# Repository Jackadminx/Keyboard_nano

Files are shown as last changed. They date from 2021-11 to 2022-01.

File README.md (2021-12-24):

# Keyboard nano

基于CH549的多功能小键盘

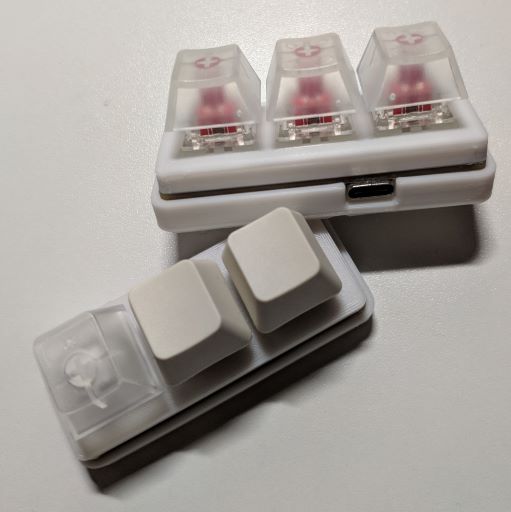
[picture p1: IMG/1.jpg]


## 功能

硬件

- 热拔插键轴
- WS2812 RGB
- CH549主控 8051
- Type-C 接口
- 3D 打印外壳

软件

- [x] 标准键盘输入，多键无冲突
- [x] 多媒体键输入
- [x] 模拟鼠标
- [x] 模拟触摸滑动、点击
- [x] 模拟 Surface Dial 轮盘
- [x] [上位机控制](https://github.com/Jackadminx/Keyboard_nano_client)
- [x] WS2812 RGB 功能
- [x] 片内 EEPROM 数据保存

## 开发平台

- Keil C51 µVision V5
- 立创EDA
- Fusion 360

## 杂项

[WS2812B library](https://github.com/Arctos6135/BeautifulRobot) 

## 提示

⚠ 焊接操作时请注意安全，上电前检查电路是否短路。本人不会对您错误操作造成的任何损失负责

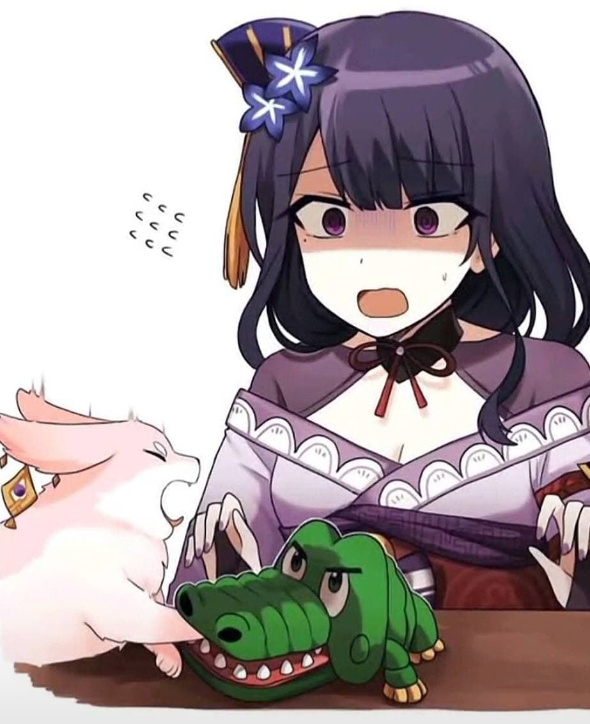
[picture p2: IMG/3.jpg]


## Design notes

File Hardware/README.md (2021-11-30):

## 原理图

https://oshwhub.com/jancgk/ch549g-dial_copy

您可以使用立创EDA进行在线查看和编辑

[Keyboard-Nano-PCB.html](./Keyboard-Nano-PCB.html)

PCB解析和BOM列表，方便焊接查找元器件。

生成工具[ InteractiveHtmlBom](https://github.com/openscopeproject/InteractiveHtmlBom)

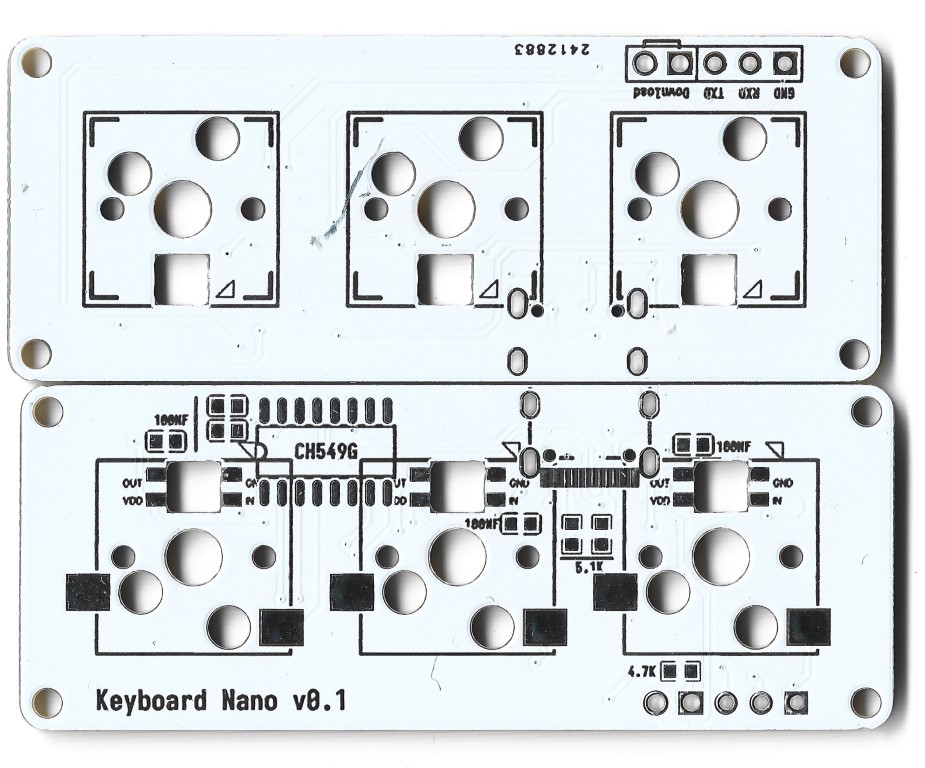
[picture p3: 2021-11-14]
Hardware/PCB (Medium).jpg

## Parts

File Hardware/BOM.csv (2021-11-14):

ID | Name | Designator | Footprint | Quantity | 备注 | Supplier Part
1 | 100nF | C1,C2,C3,C4,C5 | C0603 | 5 |  | C1591
2 | CH549G | U1 | SOIC-16_L9.9-W3.9-P1.27-LS6.0-TL | 1
3 | TYPE-C-31-M-12 | USBC1 | USB-C_SMD-TYPE-C-31-M-12 | 1 |  | C165948
4 | 4.7K | R1 | R0603 | 1 |  | C269694
5 | 5.1K | R8,R9 | R0603 | 2 |  | C23186
6 | 键盘键轴 | SW1,SW2,SW3 | CHERRY_MX_RGB | 3 | MX轴体或其脚针兼容键轴
7 | 6028RGB | SW1,SW2,SW4 | CHERRY_MX_RGB | 3 | WS2812灯珠倒装
8 | M2*5螺丝 |  |  | 4
9 | M2螺母 |  |  | 4
10 | 磁铁柱 |  |  | 4 | 直径3MM 柱长3MM 用于吸附外壳
11 | 键盘帽 |  |  | 3
12 | 热拔插底座 |  |  | 3 | 凯华kailh热拔插底座
13 | 硅胶防滑脚垫 |  |  | 4 | 防滑硅胶垫小颗粒垫片 直径6mm*厚0.5mm

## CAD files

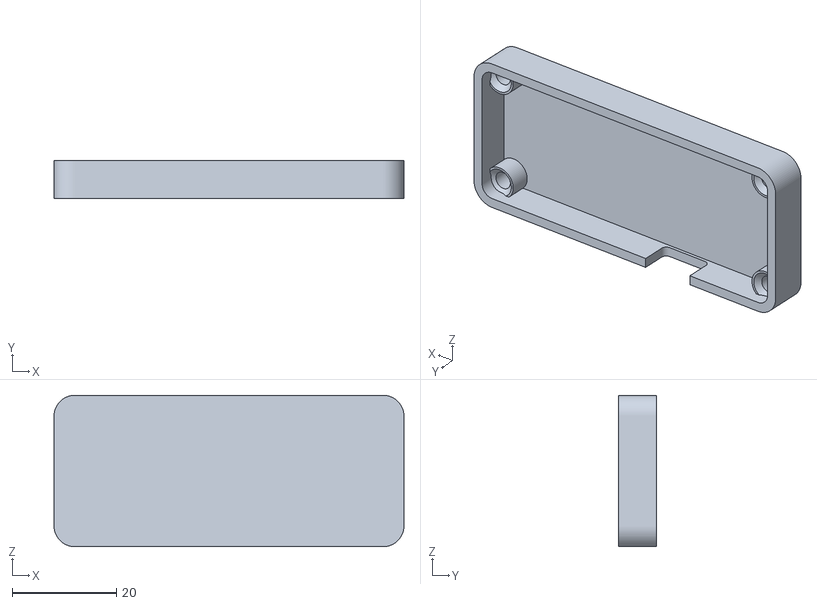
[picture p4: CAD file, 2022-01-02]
Shell/dockv2.stl
67.1 x 7.20 x 29.0

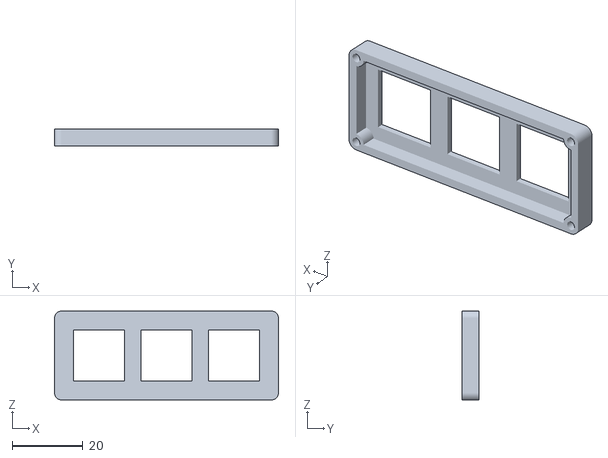
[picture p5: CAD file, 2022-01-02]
Shell/shellv2.stl
63.1 x 4.90 x 25.0

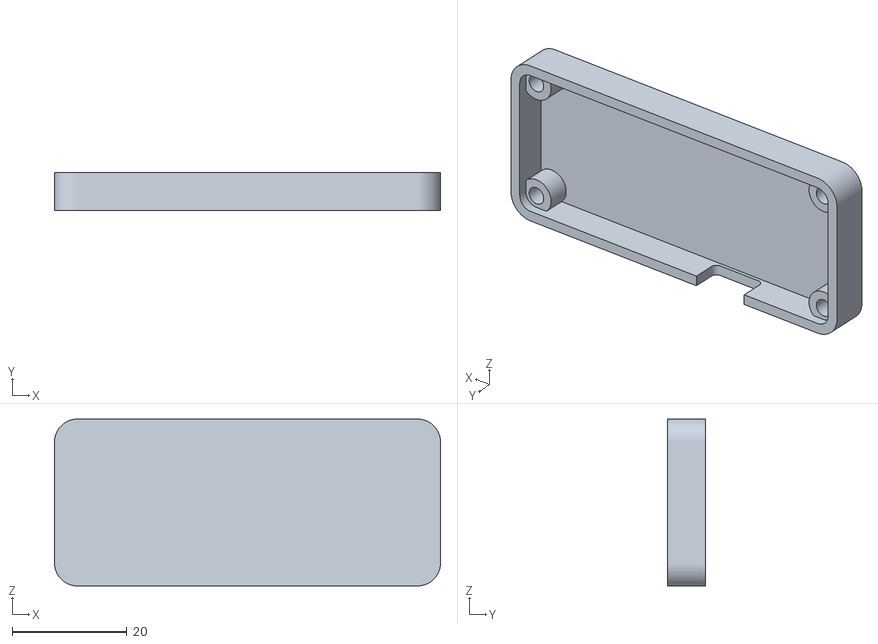
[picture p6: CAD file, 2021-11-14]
Shell/dock.stl
67.1 x 6.60 x 29.0

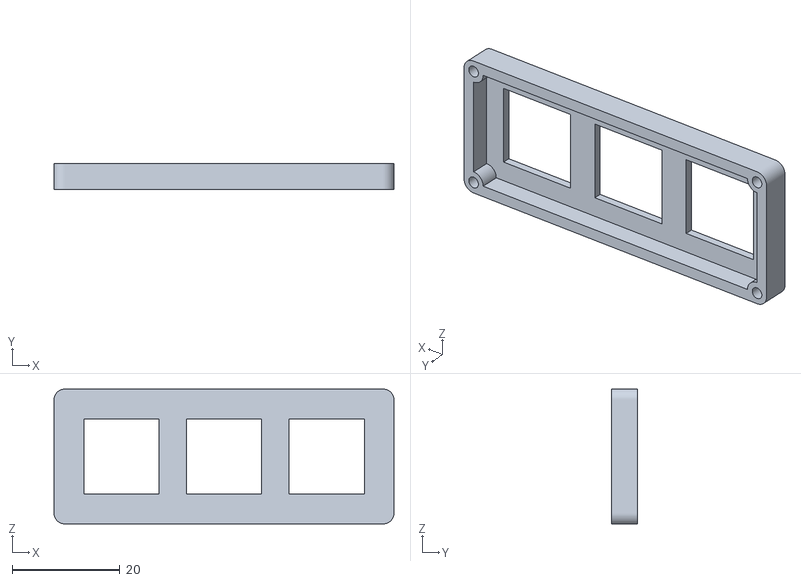
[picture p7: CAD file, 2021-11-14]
Shell/shell.stl
63.1 x 4.90 x 25.0

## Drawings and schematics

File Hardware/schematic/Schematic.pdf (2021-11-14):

# Type-C

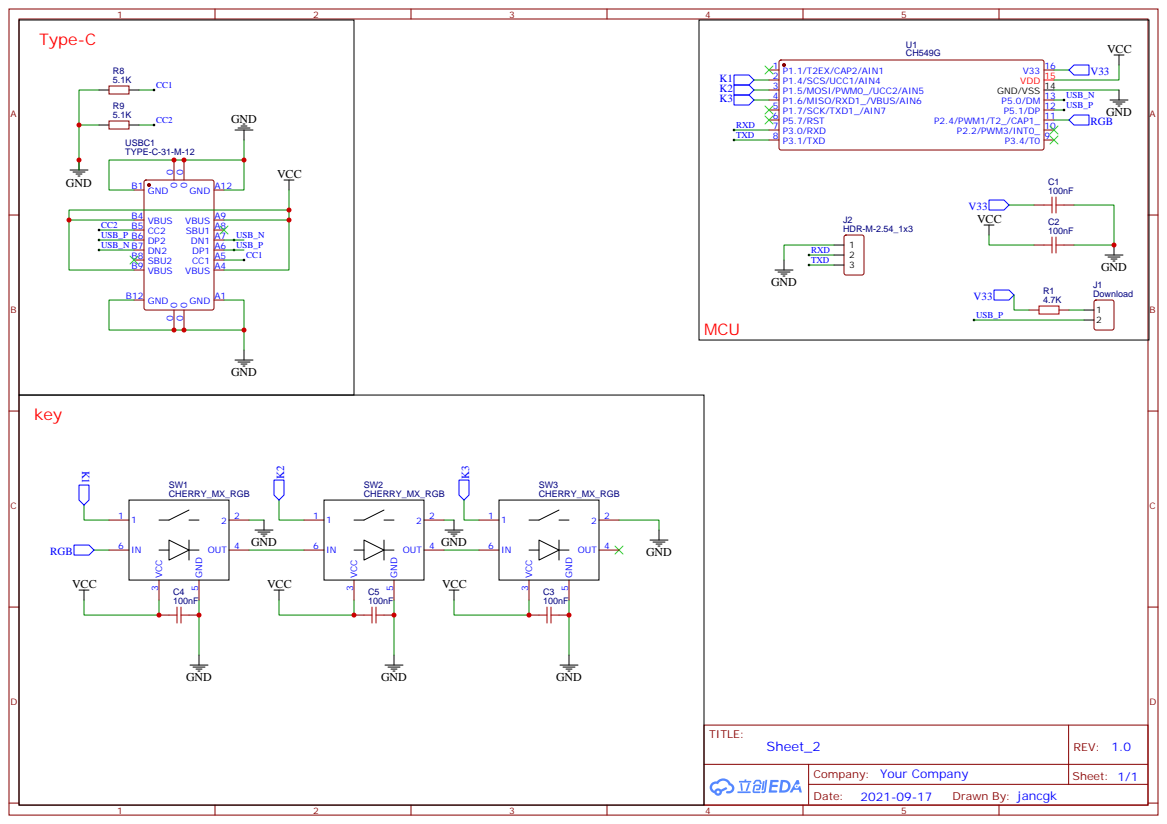
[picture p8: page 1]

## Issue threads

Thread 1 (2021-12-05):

电脑无法识别设备

meselson, 2021-12-05:
接入电脑，提示未识别的USB设备，win7、win10都是如此，无法刷入固件，请问下是什么问题？

Jackadminx, 2021-12-05:
检查type-c是否焊好，芯片第一次上电默认就会进入下载模式。
你也可以参考这里的[固件烧录步骤](https://github.com/Jackadminx/Keyboard_nano/wiki/%E5%9B%BA%E4%BB%B6%E7%83%A7%E5%BD%95%E6%AD%A5%E9%AA%A4)

Closed 2021-12-18.

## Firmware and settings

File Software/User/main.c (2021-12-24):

/********************************** (C) COPYRIGHT *******************************
* File Name          : main.C
* Author             :
* Version            : V1.0
* Date               : 2021/09/15
* Description        : CH549模拟HID兼容设备，支持中断上下传，支持控制端点上下传，支持设置全速，低速
                       注意包含DEBUG.C

                                             3键USB键盘
                                             RGB支持
                                             自定义HID功能，支持上位机修改键位
*******************************************************************************/
#include "CH549.H"
#include "DEBUG.H"
#include "GPIO.H"
#include "FlashRom.H"
#include "MATH.H"
#include "RGB.H"

#define Fullspeed
#ifdef Fullspeed
#define THIS_ENDP0_SIZE 64
#else
#define THIS_ENDP0_SIZE 8 //低速USB，中断传输、控制传输最大包长度为8
#endif
UINT8X Ep0Buffer[THIS_ENDP0_SIZE + 2] _at_ 0x0000;                  //端点0 OUT&IN缓冲区，必须是偶地址
UINT8X Ep2Buffer[2 * MAX_PACKET_SIZE + 4] _at_ THIS_ENDP0_SIZE + 2; //端点2 IN&OUT缓冲区,必须是偶地址
UINT8 SetupReq, Ready, UsbConfig;
UINT16 SetupLen;
PUINT8 pDescr;             // USB配置标志
USB_SETUP_REQ SetupReqBuf; //暂存Setup包
#define UsbSetupBuf ((PUSB_SETUP_REQ)Ep0Buffer)

sbit KEY1 = P1 ^ 4; // KEY1
sbit KEY2 = P1 ^ 5; // KEY2
sbit KEY3 = P1 ^ 6; // KEY2
#pragma NOAREGS

/*字符串描述符 略*/
/*HID类报表描述符*/
UINT8C HIDRepDesc[] =
    {

        /* keyboared */
        0x05, 0x01, // USAGE_PAGE (Generic Desktop)
        0x09, 0x06, // USAGE (Keyboard)
        0xa1, 0x01, // COLLECTION (Application)
        0x85, 0x01, // Report ID (1)
        0x05, 0x07, // USAGE_PAGE (Keyboard)
        0x19, 0xe0, // USAGE_MINIMUM (Keyboard LeftControl)
        0x29, 0xe7, // USAGE_MAXIMUM (Keyboard Right GUI)
        0x15, 0x00, // LOGICAL_MINIMUM (0)
        0x25, 0x01, // LOGICAL_MAXIMUM (1)
        0x75, 0x01, // REPORT_SIZE (1)
        0x95, 0x08, // REPORT_COUNT (8)
        0x81, 0x02, // INPUT (Data,Var,Abs)
        0x95, 0x01, // REPORT_COUNT (1)
        0x75, 0x08, // REPORT_SIZE (8)
        0x81, 0x03, // INPUT (Cnst,Var,Abs)
        0x95, 0x05, // REPORT_COUNT (5)
        0x75, 0x01, // REPORT_SIZE (1)
        0x05, 0x08, // USAGE_PAGE (LEDs)
        0x19, 0x01, // USAGE_MINIMUM (Num Lock)
        0x29, 0x05, // USAGE_MAXIMUM (Kana)
        0x91, 0x02, // OUTPUT (Data,Var,Abs)
        0x95, 0x01, // REPORT_COUNT (1)
        0x75, 0x03, // REPORT_SIZE (3)
        0x91, 0x03, // OUTPUT (Cnst,Var,Abs)
        0x95, 0x06, // REPORT_COUNT (6)
        0x75, 0x08, // REPORT_SIZE (8)
        0x15, 0x00, // LOGICAL_MINIMUM (0)
        0x25, 0xFF, // LOGICAL_MAXIMUM (255)
        0x05, 0x07, // USAGE_PAGE (Keyboard)
        0x19, 0x00, // USAGE_MINIMUM (Reserved (no event indicated))
        0x29, 0x65, // USAGE_MAXIMUM (Keyboard Application)
        0x81, 0x00, // INPUT (Data,Ary,Abs)
        0xc0,       // END_COLLECTION    /* 65 */

        /* consumer */
        0x05, 0x0c,       // USAGE_PAGE (Consumer Devices)
        0x09, 0x01,       // USAGE (Consumer Control)
        0xa1, 0x01,       // COLLECTION (Application)
        0x85, 0x02,       //   REPORT_ID (2)
        0x19, 0x00,       //   USAGE_MINIMUM (Unassigned)
        0x2a, 0x3c, 0x03, //   USAGE_MAXIMUM
        0x15, 0x00,       //   LOGICAL_MINIMUM (0)
        0x26, 0x3c, 0x03, //   LOGICAL_MAXIMUM (828)
        0x95, 0x01,       //   REPORT_COUNT (1)
        0x75, 0x10,       //   REPORT_SIZE (16)
        0x81, 0x00,       //   INPUT (Data,Ary,Abs)
        0xc0,             // END_COLLECTION  /* 25 */

        /* mouse */
        0x05, 0x01, // USAGE_PAGE (Generic Desktop)
        0x09, 0x02, // USAGE (Mouse)
        0xa1, 0x01, // COLLECTION (Application)
        0x85, 0x03, // REPORT_ID (3)
        0x09, 0x01, //   USAGE (Pointer)
        0xa1, 0x00, //   COLLECTION (Physical)
        0x05, 0x09, //     USAGE_PAGE (Button)
        0x19, 0x01, //     USAGE_MINIMUM (Button 1)
        0x29, 0x03, //     USAGE_MAXIMUM (Button 3)
        0x15, 0x00, //     LOGICAL_MINIMUM (0)
        0x25, 0x01, //     LOGICAL_MAXIMUM (1)
        0x95, 0x03, //     REPORT_COUNT (3)
        0x75, 0x01, //     REPORT_SIZE (1)
        0x81, 0x02, //     INPUT (Data,Var,Abs)
        0x95, 0x01, //     REPORT_COUNT (1)
        0x75, 0x05, //     REPORT_SIZE (5)
        0x81, 0x03, //     INPUT (Cnst,Var,Abs)
        0x05, 0x01, //     USAGE_PAGE (Generic Desktop)
        0x09, 0x30, //     USAGE (X)
        0x09, 0x31, //     USAGE (Y)
        0x09, 0x38, //		 Usage (Wheel)
        0x15, 0x81, //     LOGICAL_MINIMUM (-127)
        0x25, 0x7f, //     LOGICAL_MAXIMUM (127)
        0x75, 0x08, //     REPORT_SIZE (8)
        0x95, 0x03, //     REPORT_COUNT (3)
        0x81, 0x06, //     INPUT (Data,Var,Rel)
        0xc0,       //   END_COLLECTION
        0xc0,       // END_COLLECTION 	/* 52 + 2 */
        /*
    BYTE1字节：
    |—bit7～3：补充的常数，无意义，这里为0即可
    |—bit2: 1表示中键按下
    |—bit1: 1表示右键按下 0表示右键抬起
    |—bit0: 1表示左键按下 0表示左键抬起
    BYTE2 — X坐标变化量，与byte的bit4组成9位符号数,负数表示向左移，正数表右移。用补码表示变化量
    BYTE3 — Y坐标变化量，与byte的bit5组成9位符号数，负数表示向下移，正数表上移。用补码表示变化量
    BYTE4 — 滚轮变化。0x01表示滚轮向前滚动一格；0xFF表示滚轮向后滚动一格；0x80是个中间值，不滚动。
    */

        //    /* Vendor-out */
        //    0x06, 0xB0, 0xFF, //Usage Page (Vendor-Defined 177)
        //    0x09, 0x01,       //Usage (Vendor-Defined 1)
        //    0xA1, 0x01,       //Collection (Application)
        //    0x85, 0x04,       //REPORT_ID (4)
        //    0x09, 0x04,       //Usage (Vendor-Defined 4)
        //    0x15, 0x00,       //Logical Minimum (0)
        //    0x26, 0xFF, 0x00, //Logical Maximum (255)
        //    0x75, 0x08,       //Report Size (8)
        //    0x95, 0x40,       //Report Count (64)
        //    0x91, 0x02,       //Output (Data,Var,Abs,NWrp,Lin,Pref,NNul,NVol,Bit)
        //    0xC0,             //End Collection   /* 23      4-report=165 */

        /* Vendor-in-out */
        0x06, 0xB1, 0xFF, // Usage Page (Vendor-Defined 178)
        0x09, 0x01,       // Usage (Vendor-Defined 1)
        0xA1, 0x01,       // Collection (Application)

        0x85, 0x04,       // REPORT_ID (4)
        0x09, 0x04,       // Usage (Vendor-Defined 4)
        0x15, 0x00,       // Logical Minimum (0)
        0x26, 0xFF, 0x00, // Logical Maximum (255)
        0x75, 0x08,       // Report Size (8)
        0x95, 0x3c,       // Report Count (60)
        0x91, 0x02,       // Output (Data,Var,Abs,NWrp,Lin,Pref,NNul,NVol,Bit)

        0x09, 0x01,       //   Usage (0x01)
        0x25, 0x00,       //   Logical Maximum (0)
        0x26, 0xFF, 0x00, //	 Logical Maximum (255)
        0x75, 0x08,       //   Report Size (8)
        0x95, 0x3c,       //   Report Count (60)
        0x81, 0x02,       //   Input (Data,Var,Abs,No Wrap,Linear,Preferred State,No Null Position)

        0xC0, // End Collection   /* 37 */

        /* Touch Screen */
        0x05, 0x0d,       // USAGE_PAGE (Digitizers)
        0x09, 0x04,       // USAGE (Touch Screen)
        0xa1, 0x01,       // COLLECTION (Application)
        0x85, 0x05,       //		REPORT_ID (5)
        0x09, 0x22,       //   USAGE (Finger)
        0xa1, 0x00,       //   COLLECTION (Physical)
        0x09, 0x42,       //     USAGE (Tip Switch)
        0x15, 0x00,       //     LOGICAL_MINIMUM (0)
        0x25, 0x01,       //     LOGICAL_MAXIMUM (1)
        0x75, 0x01,       //     REPORT_SIZE (1)
        0x95, 0x01,       //     REPORT_COUNT (1)
        0x81, 0x02,       //     INPUT (Data,Var,Abs)
        0x09, 0x32,       //     Usage (In Range)
        0x15, 0x00,       //     Logical Minimum (0)
        0x25, 0x01,       //     Logical Maximum (1)
        0x81, 0x02,       //     Input (Data,Var,Abs,NWrp,Lin,Pref,NNul,Bit)
        0x09, 0x51,       //     Usage (Contact Identifier)
        0x75, 0x05,       //     Report Size (5)
        0x95, 0x01,       //     Report Count (1)
        0x16, 0x00, 0x00, //     Logical Minimum (0)
        0x26, 0x10, 0x00, //     Logical Maximum (16)
        0x81, 0x02,       //     Input (Data,Var,Abs,NWrp,Lin,Pref,NNul,Bit)
        0x09, 0x47,       //     Usage (Confidence)
        0x75, 0x01,       //     Report Size (1)
        0x95, 0x01,       //     Report Count (1)
        0x15, 0x00,       //     Logical Minimum (0)
        0x25, 0x01,       //     Logical Maximum (1)
        0x81, 0x02,       //     Input (Data,Var,Abs,NWrp,Lin,Pref,NNul,Bit)
        0x05, 0x01,       //     Usage Page (Generic Desktop)
        0x09, 0x30,       //     Usage (X)
        0x75, 0x10,       //     Report Size (16)
        0x95, 0x01,       //     Report Count (1)
        0x55, 0x0D,       //     Unit Exponent (-3)
        0x65, 0x33,       //     Unit (Eng Lin: in^3)
        0x35, 0x00,       //     Physical Minimum (0)
        0x46, 0x60, 0x17, //     Physical Maximum (5984)
        0x26, 0xFF, 0x0F, //     Logical Maximum (4095)
        0x81, 0x02,       //     Input (Data,Var,Abs,NWrp,Lin,Pref,NNul,Bit)
        0x09, 0x31,       //     Usage (Y)
        0x75, 0x10,       //     Report Size (16)
        0x95, 0x01,       //     Report Count (1)
        0x55, 0x0D,       //     Unit Exponent (-3)
        0x65, 0x33,       //     Unit (Eng Lin: in^3)
        0x35, 0x00,       //     Physical Minimum (0)
        0x46, 0x26, 0x0E, //     Physical Maximum (3622)
        0x26, 0xFF, 0x0F, //     Logical Maximum (4095)
        0x81, 0x02,       //     Input (Data,Var,Abs,NWrp,Lin,Pref,NNul,Bit)
        0xC0,             //   End Collection
        0xc0,             // END_COLLECTION                /* 102 */

        /* dial */
        0x05, 0x01,
        0x09, 0x0e,
        0xa1, 0x01,
        0x85, 0x06, //		REPORT_ID (6)
        0x05, 0x0d,
        0x09, 0x21,
        0xa1, 0x00,
        0x05, 0x09,
        0x09, 0x01,
        0x95, 0x01,
        0x75, 0x01,
        0x15, 0x00,
        0x25, 0x01,
        0x81, 0x02,
        0x05, 0x01,
        0x09, 0x37,
        0x95, 0x01,
        0x75, 0x0f,
        0x55, 0x0f,
        0x65, 0x14,
        0x36, 0xf0, 0xf1,
        0x46, 0x10, 0x0e,
        0x16, 0xf0, 0xf1,
        0x26, 0x10, 0x0e,
        0x81, 0x06,
        0xc0,
        0xC0, /* 56 */

};

/*设备描述符*/
UINT8C DevDesc[] = {0x12, 0x01, 0x00, 0x02, 0x00, 0x00, 0x00, THIS_ENDP0_SIZE,
                    //                    0x86, 0x1A, 0xE0, 0xE6, 0x00, 0x00, 0x01, 0x02, //0x86, 0x1A,VID    0xE0, 0xE6,PID
                    0x86, 0x2B, 0xE0, 0xE6, 0x00, 0x00, 0x01, 0x02,
                    0x00, 0x01};
UINT8C CfgDesc[] =
    {
        0x09, 0x02, 0x29, 0x00, 0x01, 0x01, 0x04, 0xA0, 0x32, //配置描述符
        0x09, 0x04, 0x00, 0x00, 0x02, 0x03, 0x00, 0x00, 0x05, //接口描述符
        //    0x09, 0x21, 0x00, 0x01, 0x00, 0x01, 0x22, 0x22, 0x00,       //HID类描述符 wDescriptorLength = 0x22
        0x09, 0x21, 0x01, 0x01, 0x21, 0x01, 0x22, sizeof(HIDRepDesc) & 0xFF, sizeof(HIDRepDesc) >> 8, // HID类描述符 修改wDescriptorLength 长度为0x10B

#ifdef Fullspeed
        0x07, 0x05, 0x82, 0x03, THIS_ENDP0_SIZE, 0x00, 0x01, //端点描述符(全速间隔时间改成1ms)
        0x07, 0x05, 0x02, 0x03, THIS_ENDP0_SIZE, 0x00, 0x01, //端点描述符
#else
        0x07, 0x05, 0x82, 0x03, THIS_ENDP0_SIZE, 0x00, 0x0A, //端点描述符(低速间隔时间最小10ms)
        0x07, 0x05, 0x02, 0x03, THIS_ENDP0_SIZE, 0x00, 0x0A, //端点描述符
#endif
};

// 语言描述符
UINT8C MyLangDescr[] = {0x04, 0x03, 0x09, 0x04};
// 厂家信息
UINT8C MyManuInfo[] = {0x30, 0x03, 'M', 0, 'o', 0, 'y', 0, 'u', 0, ' ', 0, 'a', 0, 't', 0, ' ', 0, 'w', 0, 'o', 0, 'r', 0, 'k', 0, ' ', 0, 'T', 0, 'e', 0, 'c', 0, 'h', 0, 'n', 0, 'o', 0, 'l', 0, 'o', 0, 'g', 0, 'y', 0}; // MoYu at work Technology
// 产品信息
UINT8C MyProdInfo[] =
    {
        0x1C,
        0x03,
        'K',
        0,
        'e',
        0,
        'y',
        0,
        'b',
        0,
        'o',
        0,
        'a',
        0,
        'r',
        0,
        'd',
        0,
        ' ',
        0,
        'N',
        0,
        'a',
        0,
        'n',
        0,
        'o',
        0,
}; //字符串描述符 Keyboard Nano 13*2bit + 2bit

// UINT8 SendHIDKey[9] = {0x01, 0x0, 0x0, 0x0, 0x0, 0x0, 0x0, 0x0, 0x53};   //每次发送按键BUFF
// UINT8 ReleaseHIDKey[9] = {0x01, 0x0, 0x0, 0x0, 0x0, 0x0, 0x0, 0x0, 0x0}; //释放按键
// UINT8 SendHIDKeyMUL[5] = {0x02, 0x00, 0x00, 0x00, 0x00};    //多媒体按键数据
// UINT8 ReleaseHIDKeyMUL[5] = {0x02, 0x00, 0x00, 0x00, 0x00}; //释放多媒体按键数据
// UINT8 SendHIDMouse[5] = {0x03, 0x00, 0x00, 0x00, 0x00};    //鼠标数据
// UINT8 ReleaseHIDMouse[5] = {0x03, 0x00, 0x00, 0x00, 0x00}; //释放鼠标点击数据
// UINT8 SendHIDTouch[6] = {0x05, 0x00, 0x00, 0x00, 0x00, 0x00}; //触摸屏数据 用于输入绝对坐标
// UINT8 SendHIDKey1[9] = {0};   //每次发送按键BUFF
// UINT8 ReleaseHIDKey1[9] = {0}; //释放按键
// UINT8 SendHIDKey2[9] = {0};   //每次发送按键BUFF
// UINT8 ReleaseHIDKey2[9] = {0}; //释放按键
// UINT8 SendHIDKey3[9] = {0};   //每次发送按键BUFF
// UINT8 ReleaseHIDKey3[9] = {0}; //释放按键

UINT8 SendHIDKey[3][9] = {{0}, {0}, {0}};
UINT8 ReleaseHIDKey[3][9] = {{0}, {0}, {0}};

UINT8 SendHID[9] = {0}; //每次发送按键BUFF

UINT8 KeyState[3] = {1, 1, 1};       //按键状态 0按下 1未按下 2长按
UINT8 BackState[3] = {1, 1, 1};      //按键上一次的状态
UINT16 KeyState_time[3] = {0, 0, 0}; //按键状态 记录长按时间

UINT8X HID_OUT_report[61] = {0}; //接收到的上位机数据

// UINT8 Get_key_1[3] = {0, 0, 0}; //按键状态 记录长按时间
UINT8 Get_mode[12] = {0, 0, 0, 0, 0, 10, 0, 0, 0, 0, 0, 1};
//# buffer[0] = 0  # 预设模式
//# buffer[1] = 0  # 保留
//# buffer[2] = 4  # 保留
//# buffer[3] = 0  # led模式组 0x00-0x06 0为关闭
//# buffer[4] = 2  # 多媒体键
//# buffer[5] = 0xff   # 按键扫描速度 单位1ms
//# buffer[6] = 0xff   # 长按识别间隔 单位100ms
//# buffer[7] = 0xff   # 屏幕分辨率 X 低位
//# buffer[8] = 0xff   # 屏幕分辨率 X 高位
//# buffer[9] = 0xff   # 屏幕分辨率 Y 低位
//# buffer[10] = 0xff   # 屏幕分辨率 Y 高位
//# buffer[10] = 0xff   # 屏幕分辨率 Y 高位
//# buffer[11] = 0   # led灯效组 0x00-0x01 0为关闭

UINT8 TH0_T, TL0_T; //定时器0数据
UINT8 Scan_ms = 10; //定时器扫描间隔 默认10ms

UINT8X UserEp2Buf[64]; //用户数据定义
UINT8 Endp2Busy = 0;
/*******************************************************************************
 * Function Name  : USBDeviceInit()
 * Description    : USB设备模式配置,设备模式启动，收发端点配置，中断开启
 * Input          : None
 * Output         : None
 * Return         : None
 *******************************************************************************/
void USBDeviceInit()
{
    IE_USB = 0;
    USB_CTRL = 0x00;        // 先设定USB设备模式
    UDEV_CTRL = bUD_PD_DIS; // 禁止DP/DM下拉电阻
#ifndef Fullspeed
    UDEV_CTRL |= bUD_LOW_SPEED; //选择低速1.5M模式
    USB_CTRL |= bUC_LOW_SPEED;
#else
    UDEV_CTRL &= ~bUD_LOW_SPEED;                             //选择全速12M模式，默认方式
    USB_CTRL &= ~bUC_LOW_SPEED;
#endif
    UEP2_T_LEN = 0;                                            //预使用发送长度一定要清空
    UEP2_DMA = Ep2Buffer;                                      //端点2数据传输地址
    UEP2_3_MOD |= bUEP2_TX_EN | bUEP2_RX_EN;                   //端点2发送接收使能
    UEP2_3_MOD &= ~bUEP2_BUF_MOD;                              //端点2收发各64字节缓冲区
    UEP2_CTRL = bUEP_AUTO_TOG | UEP_T_RES_NAK | UEP_R_RES_ACK; //端点2自动翻转同步标志位，IN事务返回NAK，OUT返回ACK
    UEP0_DMA = Ep0Buffer;                                      //端点0数据传输地址
    UEP4_1_MOD &= ~(bUEP4_RX_EN | bUEP4_TX_EN);                //端点0单64字节收发缓冲区
    UEP0_CTRL = UEP_R_RES_ACK | UEP_T_RES_NAK;                 // OUT事务返回ACK，IN事务返回NAK
    USB_DEV_AD = 0x00;
    USB_CTRL |= bUC_DEV_PU_EN | bUC_INT_BUSY | bUC_DMA_EN; // 启动USB设备及DMA，在中断期间中断标志未清除前自动返回NAK
    UDEV_CTRL |= bUD_PORT_EN;                              // 允许USB端口
    USB_INT_FG = 0xFF;                                     // 清中断标志
    USB_INT_EN = bUIE_SUSPEND | bUIE_TRANSFER | bUIE_BUS_RST;
    IE_USB = 1;
}
/*******************************************************************************
 * Function Name  : Enp2BlukIn()
 * Description    : USB设备模式端点2的批量上传
 * Input          : None
 * Output         : None
 * Return         : None
 *******************************************************************************/
void Enp2BlukIn(UINT8 *buf, UINT8 len)
{
    memcpy(Ep2Buffer + MAX_PACKET_SIZE, buf, len);           //加载上传数据
    UEP2_T_LEN = len;                                        //上传最大包长度
    UEP2_CTRL = UEP2_CTRL & ~MASK_UEP_T_RES | UEP_T_RES_ACK; //有数据时上传数据并应答ACK
}
/*******************************************************************************
 * Function Name  : DeviceInterrupt()
 * Description    : CH559USB中断处理函数
 *******************************************************************************/
void DeviceInterrupt(void) interrupt INT_NO_USB using 1 // USB中断服务程序,使用寄存器组1
{
    UINT8 i;
    UINT16 len;
    UINT8 test_report[2] = {0};
    test_report[0] = 4;
    test_report[1] = 3;

    if (UIF_TRANSFER) // USB传输完成标志
    {
        switch (USB_INT_ST & (MASK_UIS_TOKEN | MASK_UIS_ENDP))
        {
        case UIS_TOKEN_IN | 2: // endpoint 2# 端点批量上传
            UEP2_T_LEN = 0;    //预使用发送长度一定要清空
            //            UEP1_CTRL ^= bUEP_T_TOG;                                          //如果不设置自动翻转则需要手动翻转
            Endp2Busy = 0;
            UEP2_CTRL = UEP2_CTRL & ~MASK_UEP_T_RES | UEP_T_RES_NAK; //默认应答NAK
            break;

        case UIS_TOKEN_OUT | 2: // endpoint 2# 端点批量下传
            if (U_TOG_OK)       // 不同步的数据包将丢弃
            {
                if (Ep2Buffer[0] == 4 && Ep2Buffer[1] == 3) //当reportid==4 测试功能
                {
                    Enp2BlukIn(test_report, 61);
#ifdef DE_PRINTF
                    printf("[HID-handle]quick-test\n");
#endif
                }

                len = USB_RX_LEN; //接收数据长度，数据从Ep2Buffer首地址开始存放
#ifdef DE_PRINTF
                printf("[HID]OUT ");
#endif

                for (i = 0; i < len; i++)
                {
#ifdef DE_PRINTF
                    printf("0x%02x ", (UINT16)Ep2Buffer[i]); //遍历OUT数据
#endif

                    if (Ep2Buffer[0] == 0x04) //当reportid==4
                    {
                        HID_OUT_report[i] = Ep2Buffer[i]; //赋值到HID_OUT_report
                    }

                    //                        Ep2Buffer[MAX_PACKET_SIZE + i] = Ep2Buffer[i] ^ 0xFF; // OUT数据取反到IN由计算机验证
                }
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
void main()
{
    CfgFsys();    // CH549时钟选择配置
    mDelaymS(10); //修改主频等待内部晶振稳定,必加
    mInitSTDIO(); //串口0初始化
#ifdef DE_PRINTF
    printf("[SYS]CLOCK_CFG=0x%02x\r\n", (UINT16)CLOCK_CFG);
    printf("[SYS]PowerOn ...\r\n");
    printf(".......................\n");
    printf("    Keyboard\n");
    printf("    Nano\n");
    printf("    Ver0.2.3a\n");
    printf(".......................\n");
#endif
    USBDeviceInit(); // USB设备模式初始化
    EA = 1;          //允许单片机中断

    GPIO_Init(PORT1, PIN4, MODE3); // P1.4上拉输入 KEY1
    GPIO_Init(PORT1, PIN5, MODE3); // P1.5上拉输入 KEY2
    GPIO_Init(PORT1, PIN6, MODE3); // P1.6上拉输入 KEY3
    GPIO_Init(PORT2, PIN4, MODE3); // P2.4上拉 RGB

    mDelaymS(600); //等待USB中断完成

    mode_flash(0);                 //读取flash中mode数据
    InitT0();                      //按键扫描间隔
    led_flash(0, 0, Get_mode[3]);  //读取flash中led数据
    LED_effect_init(Get_mode[11]); //    LED_effect_init(Get_mode[11]); //设置灯效组
    key_flash(0);                  //读取flash中key数据
    wd2812b_driver();              // wd2812加载

    while (1)
    {
        button_driver();
        LED_effects_fades();

        if (HID_OUT_report[0] == 0x04)
        {
            report_handle();
            HID_OUT_report[0] = 0x00;
        }
    }
}

/*******************************************************************************
* Function Name  : mTimer0Interrupt()
* Description    : CH549定时计数器0定时计数器中断 处理函数
                    定时器溢出时间由Scan_ms定义
*******************************************************************************/
void mTimer0Interrupt(void) interrupt 1
{
    //重启定时器
    TH0 = TH0_T;
    TL0 = TH0_T;
    button_read();
}

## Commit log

2021-11-14 首次提交
    [BOM.csv, dock.stl, shell.stl]
2021-11-16 原理图在线编辑
2021-11-30 PCB图表
2021-12-24 添加按动灯效
    添加按动灯效
    更换WS2812B驱动
2022-01-02 优化外壳设计
    [dockv2.stl, shellv2.stl]
